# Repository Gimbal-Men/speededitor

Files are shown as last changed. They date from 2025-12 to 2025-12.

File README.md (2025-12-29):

One-Handed DaVinci Resolve Hackpad
This project is a one-handed hackpad designed specifically to improve the video editing workflow in DaVinci Resolve, with a strong focus on the Cut Page and Edit Page.

Input Layout & Functions:
The hackpad consists of 12 mechanical keys and 2 rotary encoders.

Undo	
Previous Cut
Next Cut
Up Track
Down Track
In/Out
Cut
Ripple Delete
Append

Encoder 1 (Jog / Playback):

Rotate: Move timeline (coarse)

Press: Play / Pause

Press + Rotate: Move timeline (fine)

Encoder 2 (Timeline / Clip):

Rotate: Timeline zoom

Press: Select clip

Press + Rotate: Move selected clip

Schematic:



PCB Design:



Case Design:









Materials:
Seeed XIAO RP2040	1x
MX-style mechanical switches 12x
EC11 rotary encoders	2x
1N4148 diodes (through-hole) 12x
Blank DSA keycaps	12x
M3x16mm screws	4x
M3 heatset inserts	4x
3D printed case parts	1 set

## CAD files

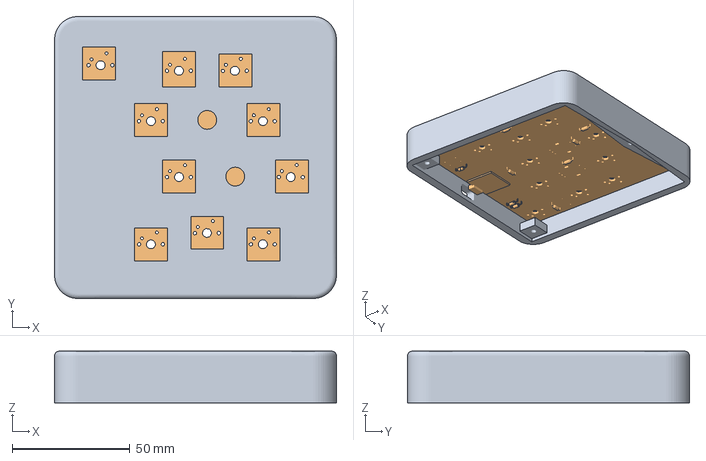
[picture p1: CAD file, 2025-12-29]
CAD/speededitor.3mf
120.0 x 120.0 x 22.0 mm
Körper1
pcb (11) (1)

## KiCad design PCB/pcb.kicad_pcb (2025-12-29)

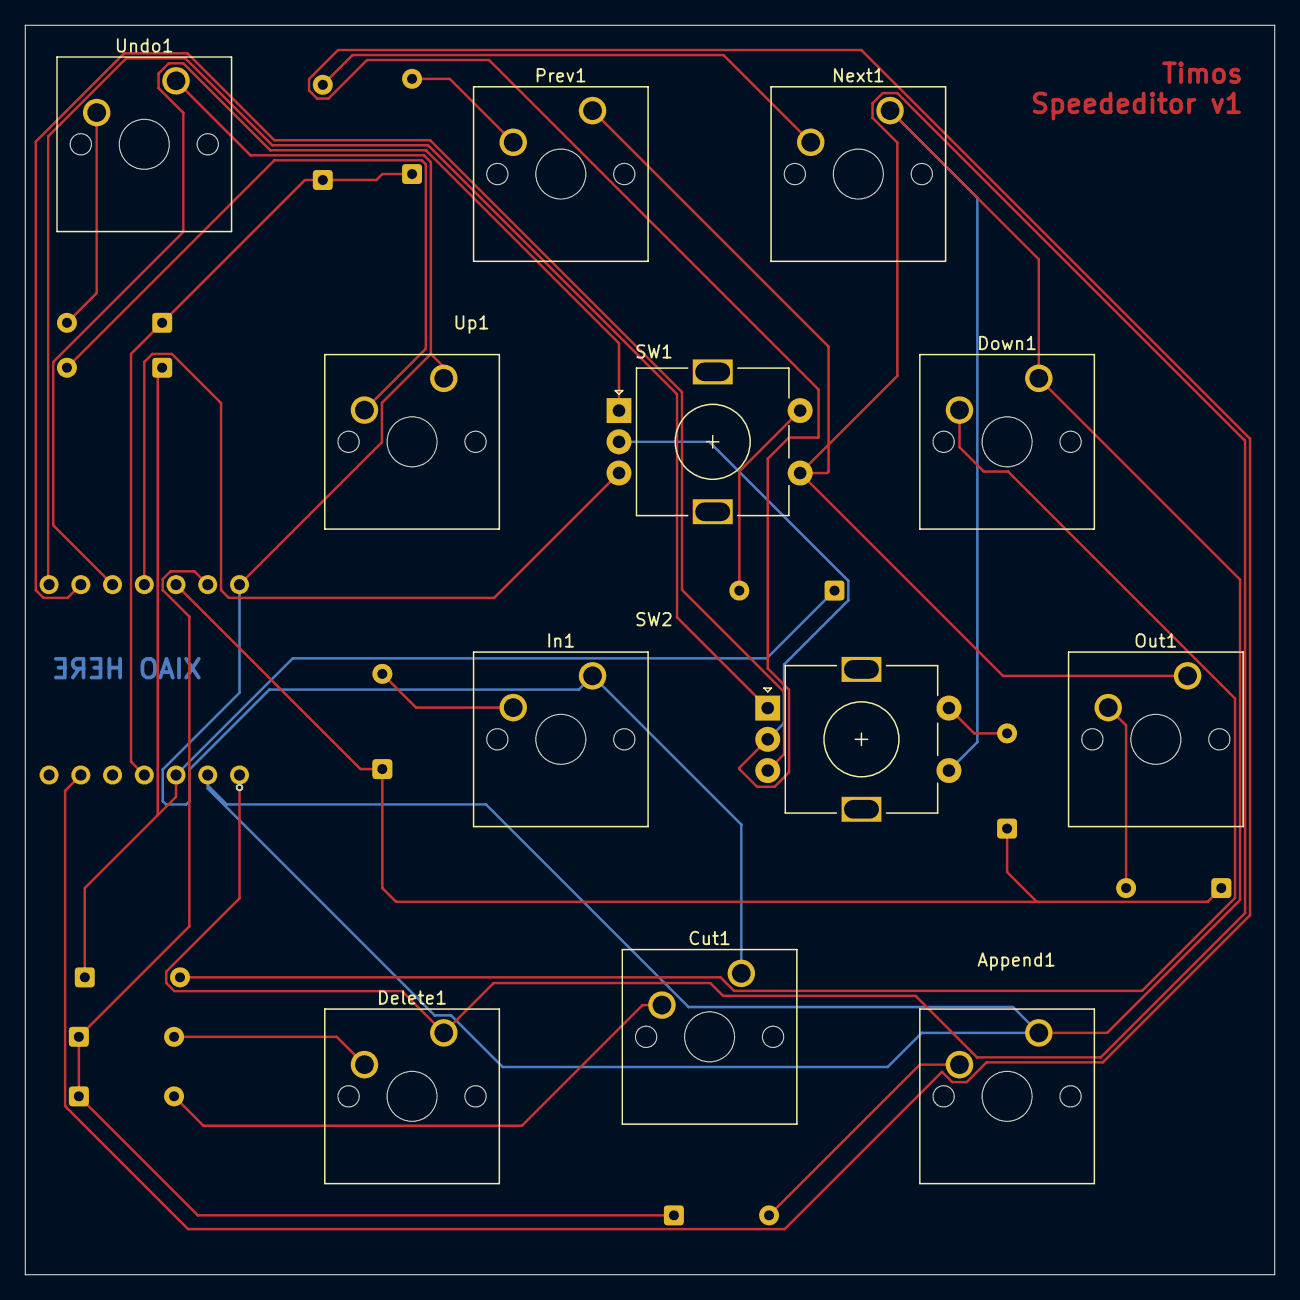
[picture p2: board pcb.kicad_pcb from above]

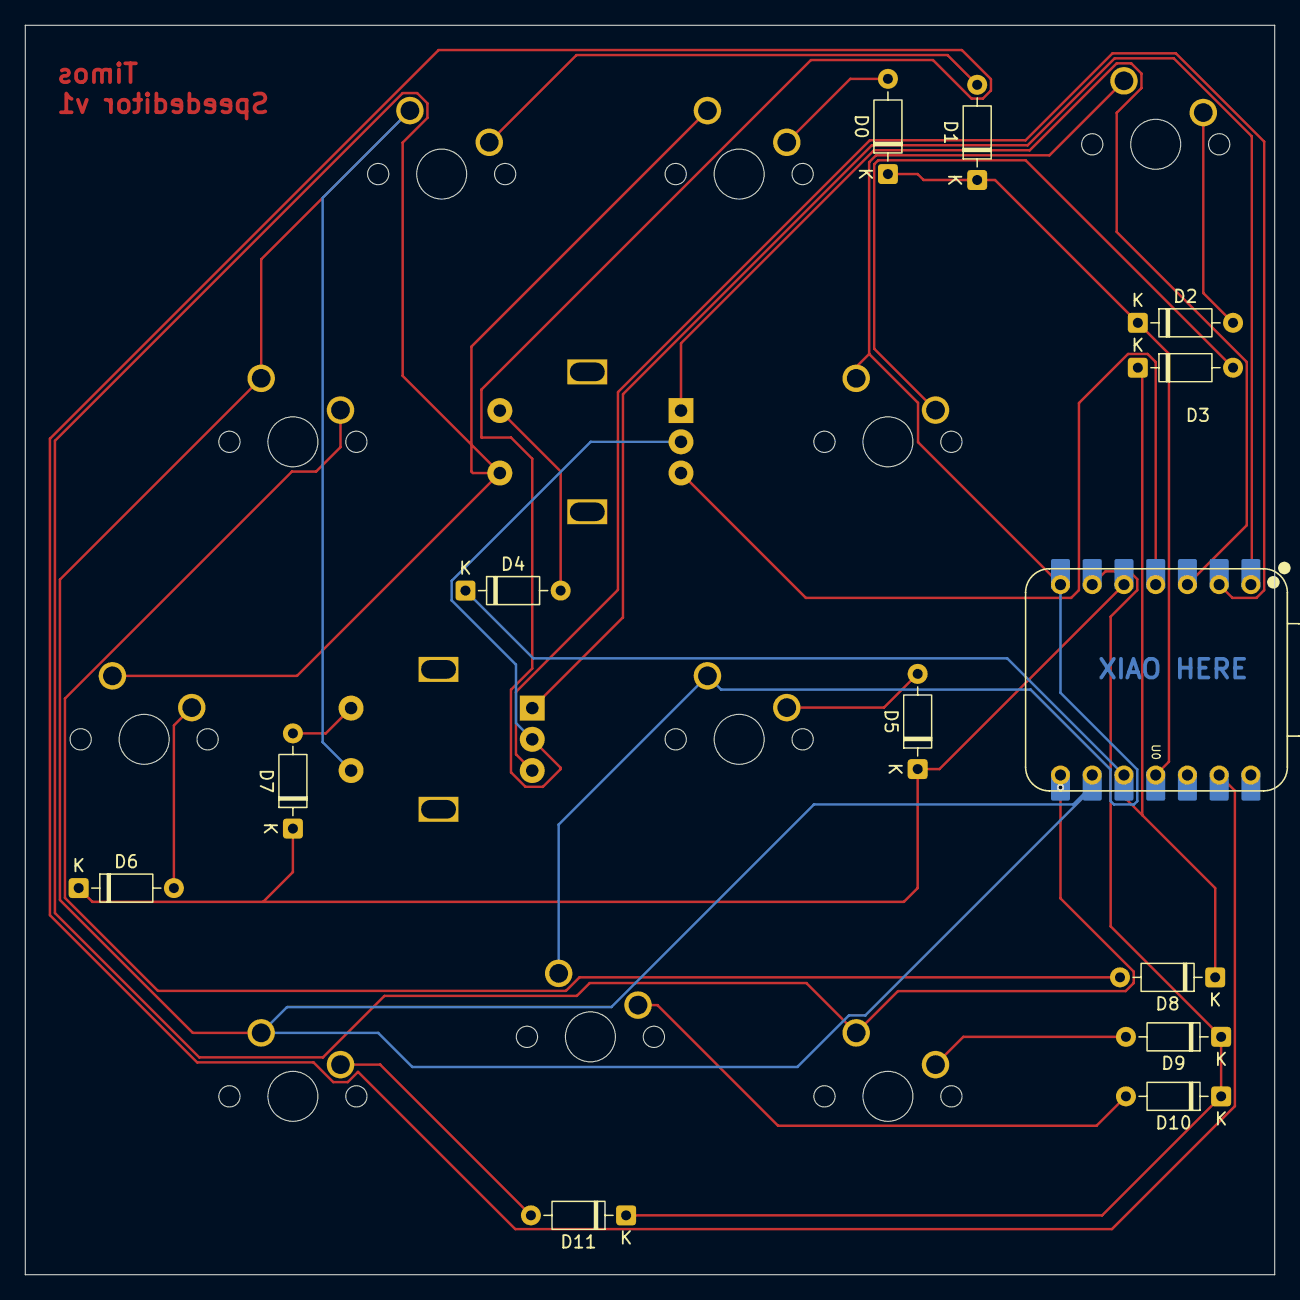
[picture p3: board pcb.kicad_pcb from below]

Board: 2 copper layers, 100.0 x 100.0 mm, 25 parts (13 on the bottom side), 24 nets.

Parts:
Append1: SW_Push; SW_Cherry_MX_1.00u_PCB
Cut1: SW_Push; SW_Cherry_MX_1.00u_PCB
D0, D1, D2, D3, D4, D5, D6, D7, D8, D9, D10, D11: 1N4148; D_DO-35_SOD27_P7.62mm_Horizontal
Delete1: SW_Push; SW_Cherry_MX_1.00u_PCB
Down1: SW_Push; SW_Cherry_MX_1.00u_PCB
In1: SW_Push; SW_Cherry_MX_1.00u_PCB
Next1: SW_Push; SW_Cherry_MX_1.00u_PCB
Out1: SW_Push; SW_Cherry_MX_1.00u_PCB
Prev1: SW_Push; SW_Cherry_MX_1.00u_PCB
SW1: Jog; RotaryEncoder_Alps_EC11E-Switch_Vertical_H20mm
SW2: ENC 2; RotaryEncoder_Alps_EC11E-Switch_Vertical_H20mm
U0: XIAO-RP2040-DIP
Undo1: SW_Push; SW_Cherry_MX_1.00u_PCB
Up1: SW_Push; SW_Cherry_MX_1.00u_PCB

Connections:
/COL0: Cut1.1, In1.1, U0.7 (GPIO0/TX), Undo1.1, Up1.1
/COL1: Delete1.1, Out1.1, Prev1.1, SW1.S1, U0.8 (GPIO1/RX)
/COL2: Append1.1, Down1.1, Next1.1, SW2.S1, U0.9 (GPIO2/SCK)
/ROW0: D0.1 (K), D1.1 (K), D2.1 (K), U0.11 (GPIO3/MOSI)
/ROW1: D3.1 (K), D4.1 (K), D8.1 (K), U0.10 (GPIO4/MISO)
/ROW2: D5.1 (K), D6.1 (K), D7.1 (K), U0.5 (GPIO6/SDA)
/ROW3: D9.1 (K), D10.1 (K), D11.1 (K), U0.6 (GPIO7/SCL)
GND: SW1.C, SW2.C, U0.13 (GND)
unnamed: D2.2 (A), Undo1.2
unnamed: D3.2 (A), Up1.2
unnamed: D5.2 (A), In1.2
unnamed: Cut1.2, D10.2 (A)
unnamed: D0.2 (A), Prev1.2
unnamed: D4.2 (A), SW1.S2
unnamed: D6.2 (A), Out1.2
unnamed: D9.2 (A), Delete1.2
unnamed: D1.2 (A), Next1.2
unnamed: D8.2 (A), Down1.2
unnamed: D7.2 (A), SW2.S2
unnamed: Append1.2, D11.2 (A)
unnamed: SW2.A, U0.1 (GPIO26/ADC0/A0)
unnamed: SW2.B, U0.2 (GPIO27/ADC1/A1)
unnamed: SW1.A, U0.3 (GPIO28/ADC2/A2)
unnamed: SW1.B, U0.4 (GPIO29/ADC3/A3)
